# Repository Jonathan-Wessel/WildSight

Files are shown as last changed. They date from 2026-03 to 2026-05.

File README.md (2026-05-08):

# WildSights Rhino Detection Camera Node

This project is an ESP32-S3 wildlife monitoring camera node that detects rhinos using an Edge Impulse object detection model. The device is triggered by a PIR motion sensor, captures a grayscale image, runs inference on-device, saves the captured image to an SD card, and sends a LoRaWAN uplink message with the detection result.

The project is currently configured for the `ESP32S3-EYE` camera model.

---

## Features

- PIR motion-triggered image capture
- ESP32-S3 camera support
- Edge Impulse object detection
- Rhino detection using bounding box results
- Grayscale QVGA camera capture
- SD card image saving as JPEG
- LoRaWAN uplinks using LMIC
- IR LED control for low-light image capture
- FreeRTOS task for image capture and inference

---

## Important Board Manager Version

Use the following ESP32 board package version:

```text
ESP32 by Espressif Systems version 2.0.17
```

In the Arduino IDE:

1. Open **Tools > Board > Boards Manager**
2. Search for **esp32**
3. Install **esp32 by Espressif Systems**
4. Select version **2.0.17**

Using a newer or different ESP32 board package version may cause compatibility issues with the camera, PSRAM, SD card, or libraries.

---

## Hardware Requirements

- ESP32-S3 camera board
- ESP32S3-EYE compatible camera pin configuration
- PIR motion sensor
- IR LED or IR illuminator
- Light sensor
- SD card
- LoRa radio module
- LoRaWAN gateway
- LoRaWAN network server, such as The Things Network

---

## Software Requirements

- Arduino IDE
- ESP32 Arduino board package version `2.0.17`
- MCCI LoRaWAN LMIC library
- Edge Impulse Arduino library exported from the Edge Impulse project
- ESP32 camera support
- SD_MMC support

The sketch also requires these project files:

```cpp
#include "camera_pins.h"
#include "sd_read_write.h"
```

Make sure these files are included in the sketch folder or are available through the correct library or example source.

---

## Recommended Arduino IDE Settings

| Setting | Value |
|---|---|
| Board package | ESP32 by Espressif Systems `2.0.17` |
| Board | ESP32S3 Dev Module or compatible ESP32-S3 camera board |
| PSRAM | Enabled |
| Upload speed | 921600 or lower if upload fails |
| Serial monitor baud | 115200 |
| Partition scheme | Huge APP or another large-app partition |

The exact board option may depend on the ESP32-S3 camera board being used.

---

## Pin Configuration

### Sensor and Output Pins

| Function | GPIO |
|---|---:|
| PIR sensor | GPIO 1 |
| IR LED | GPIO 2 |
| Light sensor | GPIO 46 |

### LoRa Radio Pins

| Function | GPIO |
|---|---:|
| NSS / CS | GPIO 3 |
| RESET | GPIO 14 |
| DIO0 | GPIO 20 |
| DIO1 | GPIO 21 |
| MISO | GPIO 47 |
| MOSI | GPIO 19 |
| SCK | GPIO 45 |

These pins are defined in the sketch:

```cpp
#define GPIO_PIR         1
#define GPIO_IRLED       2
#define GPIO_LIGHTSENSOR 46

#define PIN_NSS   3
#define PIN_RST   14
#define PIN_DIO0  20
#define PIN_DIO1  21

#define LORA_MISO  47
#define LORA_MOSI  19
#define LORA_SCK   45
```

Check that the pin definitions match the actual wiring of your ESP32-S3 board and LoRa module.

---

## Camera Configuration

The project is configured for:

```cpp
#define CAMERA_MODEL_ESP32S3_EYE
```

The camera captures grayscale QVGA images:

```cpp
.pixel_format = PIXFORMAT_GRAYSCALE,
.frame_size   = FRAMESIZE_QVGA,
```

This means the camera captures images at:

```text
320 x 240
```

The frame buffer is stored in PSRAM:

```cpp
.fb_location = CAMERA_FB_IN_PSRAM
```

Because of this, PSRAM must be enabled in the Arduino IDE board settings.

---

## Edge Impulse Model

The project uses an exported Edge Impulse model:

```cpp
#include <Wildsights_rhino_md_conf.5_inferencing.h>
```

The classifier is initialized in `setup()`:

```cpp
run_classifier_init();
```

Inference is run using:

```cpp
EI_IMPULSE_ERROR err = run_classifier(&signal, &result, false);
```

The code checks the Edge Impulse bounding box results for the label:

```text
rhino
```

The label comparison happens here:

```cpp
if (strcmp(bb.label, "rhino") == 0)
```

If your Edge Impulse model uses a different label name, update this line in the sketch.

---

## Detection Threshold

The rhino detection confidence threshold is currently set to `0.7`:

```cpp
if (rhino && best.value >= 0.7) {
```

Threshold behavior:

| Threshold | Behavior |
|---|---|
| `0.5` | More sensitive, but may create more false positives |
| `0.7` | Current default |
| `0.9` | More strict, but may miss some detections |

---

## LoRaWAN Configuration

The sketch uses OTAA activation with:

- Join EUI
- Device EUI
- App Key

These values are defined in the code:

```cpp
static const uint8_t JOIN_EUI_BE[8] = { ... };
static const uint8_t DEV_EUI_BE[8]  = { ... };
static const uint8_t APP_KEY[16]    = { ... };
```

Do not publish real LoRaWAN credentials in a public repository.

For public repositories, replace real credentials with placeholder values:

```cpp
static const uint8_t JOIN_EUI_BE[8] = {
  0x00, 0x00, 0x00, 0x00,
  0x00, 0x00, 0x00, 0x00
};

static const uint8_t DEV_EUI_BE[8] = {
  0x00, 0x00, 0x00, 0x00,
  0x00, 0x00, 0x00, 0x00
};

static const uint8_t APP_KEY[16] = {
  0x00, 0x00, 0x00, 0x00,
  0x00, 0x00, 0x00, 0x00,
  0x00, 0x00, 0x00, 0x00,
  0x00, 0x00, 0x00, 0x00
};
```

If real keys were shared publicly, regenerate them in your LoRaWAN network server.

---

## LMIC Configuration

The LoRa radio uses custom SPI pins:

```cpp
SPI.begin(LORA_SCK, LORA_MISO, LORA_MOSI, PIN_NSS);
```

LMIC is initialized in `setup()`:

```cpp
os_init();
LMIC_reset();
LMIC_selectSubBand(1);
LMIC_setAdrMode(0);
LMIC_setClockError(MAX_CLOCK_ERROR * 1 / 100);
LMIC_startJoining();
```

The selected LoRaWAN sub-band is:

```cpp
LMIC_selectSubBand(1);
```

Make sure this matches your LoRaWAN region, gateway, and network server configuration.

---

## LoRaWAN Uplink Messages

When a rhino is detected, the node sends:

```text
Rhino detected
```

When no rhino is detected, the node sends:

```text
No Rhino
```

Messages are sent on LoRaWAN port `1`:

```cpp
LMIC_setTxData2(1, buf, (u1_t)len, 0);
```

---

## SD Card Image Saving

Images are saved to:

```text
/camera/
```

The directory is created during setup:

```cpp
createDir(SD_MMC, "/camera");
```

Images are saved using an incrementing file number:

```text
/camera/1.jpg
/camera/2.jpg
/camera/3.jpg
```

Both rhino detections and non-detections are currently saved.

---

## How It Works

1. The ESP32-S3 starts the serial monitor, SD card, camera, Edge Impulse model, LoRa radio, and PIR interrupt.
2. The PIR sensor triggers an interrupt when motion is detected.
3. A FreeRTOS inference task wakes up.
4. The PIR signal is debounced.
5. The IR LED turns on.
6. The camera captures a grayscale image.
7. The image is resized to the Edge Impulse model input size.
8. The Edge Impulse classifier runs on the ESP32-S3.
9. The result is checked for a bounding box labeled `rhino`.
10. If the confidence is at least `0.7`, a rhino detection is confirmed.
11. The image is saved to the SD card.
12. A LoRaWAN message is queued.
13. The IR LED turns off.
14. The system waits through a cooldown period before responding to another trigger.

---

## Main Runtime Loop

The main `loop()` only runs the LMIC event loop:

```cpp
void loop() {
  os_runloop_once();
}
```

Image capture and inference are handled in a separate FreeRTOS task:

```cpp
xTaskCreatePinnedToCore(
  inferenceTask,
  "inferenceTask",
  32768,
  nullptr,
  1,
  &inferTaskHandle,
  1
);
```

---

## Serial Monitor

Open the Serial Monitor at:

```text
115200 baud
```

Startup messages include:

```text
PSRAM found: YES
Free heap:
Free PSRAM:
Camera PID:
Setup complete.
```

LoRaWAN messages include:

```text
Joining...
JOINED!
Uplink queued: Rhino detected
TX complete
```

Inference messages include:

```text
INFERENCE: running classifier
INFERENCE: done classifier
Rhino DETECTED
No rhino.
```

---

## Troubleshooting

### Camera Init Failed

Check the following:

- The correct camera model is selected
- `camera_pins.h` matches your board
- PSRAM is enabled
- ESP32 board package version is `2.0.17`
- The camera ribbon cable is connected correctly

### Failed to Allocate Snapshot Buffer

Check the following:

- PSRAM is enabled
- The board has PSRAM
- The Edge Impulse model is not too large
- The partition scheme provides enough app space

### Device Does Not Join LoRaWAN

Check the following:

- Join EUI
- Device EUI
- App Key
- EUI byte order
- LMIC region
- LMIC sub-band
- Gateway frequency plan
- LoRa radio wiring
- Antenna connection

### SD Card Images Are Not Saving

Check the following:

- SD card is inserted
- SD card is formatted correctly
- `sdmmcInit()` succeeds
- The `/camera` directory exists
- `sd_read_write.h` is included correctly

### Classifier Always Returns No Rhino

Check the following:

- The model label is exactly `rhino`
- The detection threshold is not too high
- The camera image orientation is correct
- The IR LED provides enough illumination
- The training data matches the deployment environment
- The model was exported correctly from Edge Impulse

---

## Notes

The function:

```cpp
saveGrayJpegWithBox()
```

saves the grayscale camera frame as a JPEG image.

In the current version of the sketch, the bounding box is printed to the Serial Monitor but is not drawn onto the saved image.

The bounding box output is printed here:

```cpp
Serial.printf(
  "Rhino DETECTED label = %s : conf=%.3f box(x=%u y=%u w=%u h=%u)\n",
  best.label,
  best.value,
  best.x,
  best.y,
  best.width,
  best.height
);
```

---

## Deployment Notes

- Use a weatherproof enclosure for outdoor deployment.
- Protect the camera lens, PIR sensor, and electronics from rain.
- Use a stable power supply.
- Connect the LoRa antenna before transmitting.
- Test the camera, SD card, Edge Impulse model, and LoRaWAN join process before field deployment.
- Do not publish real LoRaWAN credentials.

---

## License

Add the project license here.

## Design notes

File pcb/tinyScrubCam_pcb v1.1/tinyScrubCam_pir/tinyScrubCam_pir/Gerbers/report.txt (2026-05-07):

Warning: Width correction constrained.  The width correction value must be in the range of [0.000001 mm; 0.199999 mm] for the current design rules.
Plotted to '/Users/ethanquach/Desktop/tinyScrubCam_pir/tinyScrubCam_pir/tinyScrubCam_pir-F_Cu.gbr'.
Plotted to '/Users/ethanquach/Desktop/tinyScrubCam_pir/tinyScrubCam_pir/tinyScrubCam_pir-B_Cu.gbr'.
Plotted to '/Users/ethanquach/Desktop/tinyScrubCam_pir/tinyScrubCam_pir/tinyScrubCam_pir-F_Paste.gbr'.
Plotted to '/Users/ethanquach/Desktop/tinyScrubCam_pir/tinyScrubCam_pir/tinyScrubCam_pir-B_Paste.gbr'.
Plotted to '/Users/ethanquach/Desktop/tinyScrubCam_pir/tinyScrubCam_pir/tinyScrubCam_pir-F_Silkscreen.gbr'.
Plotted to '/Users/ethanquach/Desktop/tinyScrubCam_pir/tinyScrubCam_pir/tinyScrubCam_pir-B_Silkscreen.gbr'.
Plotted to '/Users/ethanquach/Desktop/tinyScrubCam_pir/tinyScrubCam_pir/tinyScrubCam_pir-F_Mask.gbr'.
Plotted to '/Users/ethanquach/Desktop/tinyScrubCam_pir/tinyScrubCam_pir/tinyScrubCam_pir-B_Mask.gbr'.
Plotted to '/Users/ethanquach/Desktop/tinyScrubCam_pir/tinyScrubCam_pir/tinyScrubCam_pir-Edge_Cuts.gbr'.
Plotted to '/Users/ethanquach/Desktop/tinyScrubCam_pir/tinyScrubCam_pir/tinyScrubCam_pir-F_Courtyard.gbr'.
Created Gerber job file '/Users/ethanquach/Desktop/tinyScrubCam_pir/tinyScrubCam_pir/tinyScrubCam_pir-job.gbrjob'.
Info: Done.

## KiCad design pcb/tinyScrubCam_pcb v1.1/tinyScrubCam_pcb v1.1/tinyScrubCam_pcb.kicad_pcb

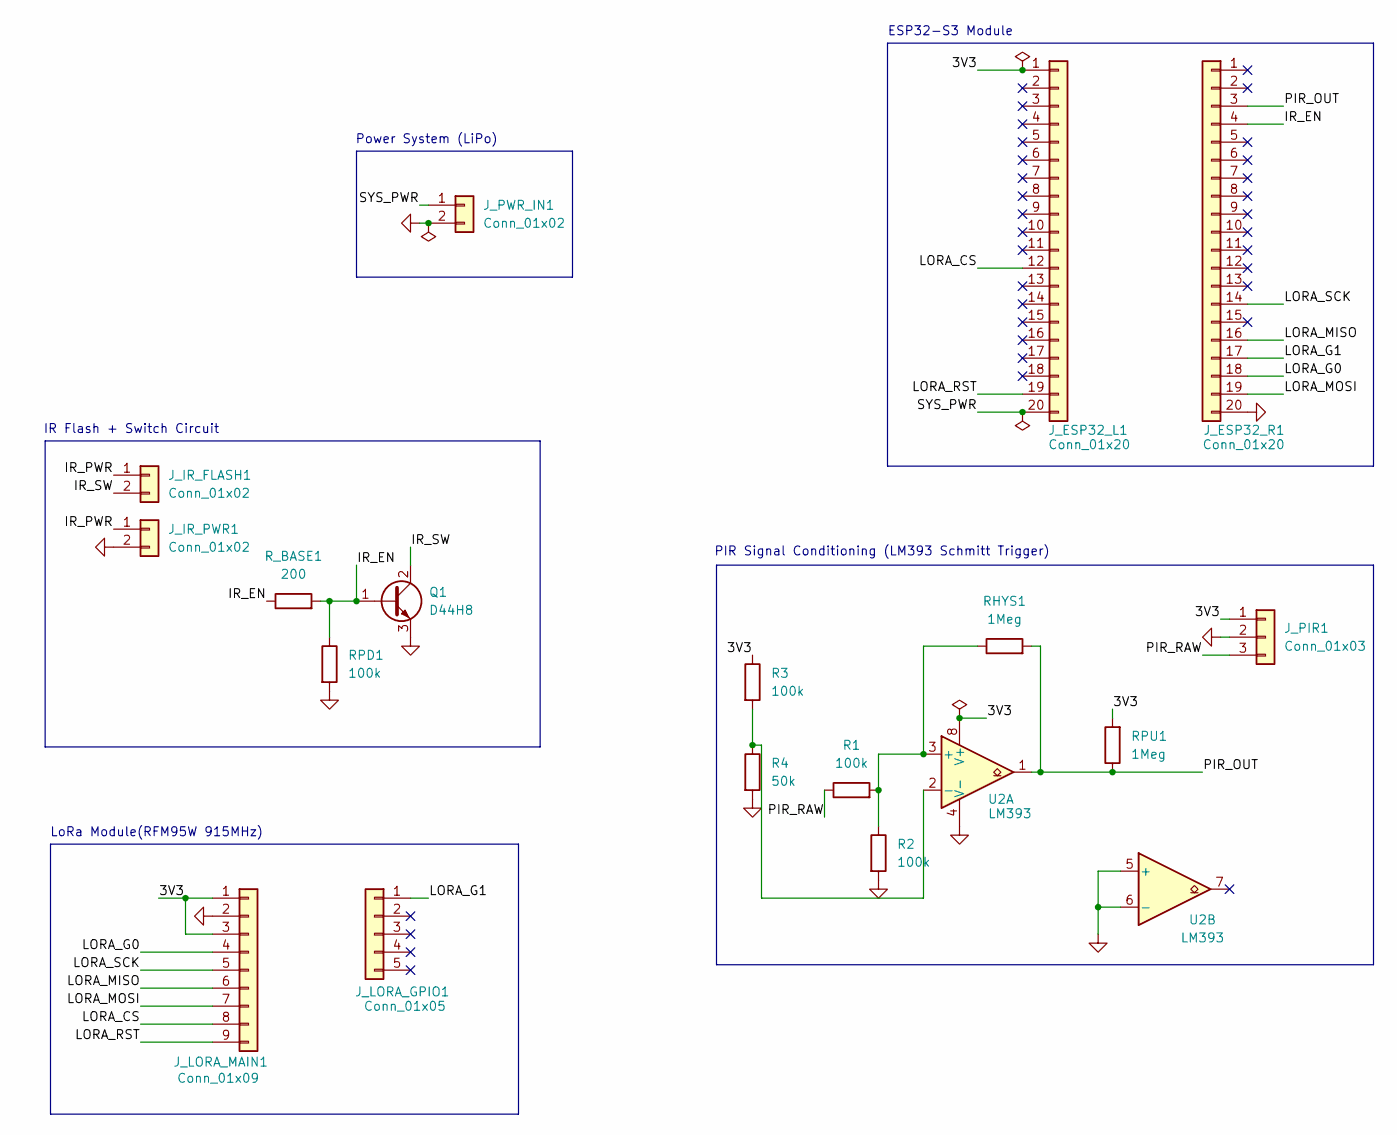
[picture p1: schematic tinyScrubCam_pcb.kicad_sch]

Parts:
J_ESP32_L1, J_ESP32_R1: Conn_01x20; PinHeader_1x20_P2.54mm_Vertical
J_IR_FLASH1: Conn_01x02; PinHeader_1x02_P2.54mm_Vertical
J_IR_PWR1: Conn_01x02; PinHeader_1x02_P2.54mm_Vertical
J_LORA_GPIO1: Conn_01x05; PinHeader_1x05_P2.54mm_Vertical
J_LORA_MAIN1: Conn_01x09; PinHeader_1x09_P2.54mm_Vertical
J_PIR1: Conn_01x03; PinSocket_1x03_P2.54mm_Vertical
J_PWR_IN1: Conn_01x02; JST_PH_B2B-PH-K_1x02_P2.00mm_Vertical
Q1: D44H8; TO-220-3_Vertical
R1, R2, R3: 100k; R_Axial_DIN0207_L6.3mm_D2.5mm_P10.16mm_Horizontal
R4: 50k; R_Axial_DIN0207_L6.3mm_D2.5mm_P10.16mm_Horizontal
RHYS1: 1Meg; R_Axial_DIN0207_L6.3mm_D2.5mm_P10.16mm_Horizontal
RPD1: 100k; R_Axial_DIN0207_L6.3mm_D2.5mm_P10.16mm_Horizontal
RPU1: 1Meg; R_Axial_DIN0207_L6.3mm_D2.5mm_P10.16mm_Horizontal
R_BASE1: 200; R_Axial_DIN0207_L6.3mm_D2.5mm_P10.16mm_Horizontal
U2: LM393

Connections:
/3V3: J_ESP32_L1.1 (3V3), J_LORA_MAIN1.1 (3V3), J_LORA_MAIN1.3 (EN), J_PIR1.1, R3.1, RPU1.2, U2.8 (V+); also elsewhere on the board
/IR_EN: J_ESP32_R1.4 (GPIO2), Q1.1 (B), RPD1.1, R_BASE1.1, R_BASE1.2
/IR_PWR: J_IR_FLASH1.1, J_IR_PWR1.1
/IR_SW: J_IR_FLASH1.2, Q1.2 (C)
/LORA_CS: J_ESP32_L1.12 (GPIO3), J_LORA_MAIN1.8 (CS)
/LORA_G0: J_ESP32_R1.18 (GPIO20), J_LORA_MAIN1.4 (GPIO0)
/LORA_G1: J_ESP32_R1.17 (GPIO21), J_LORA_GPIO1.1 (GPIO1_1)
/LORA_MISO: J_ESP32_R1.16 (GPIO47), J_LORA_MAIN1.6 (MISO)
/LORA_MOSI: J_ESP32_R1.19 (GPIO19), J_LORA_MAIN1.7 (MOSI)
/LORA_RST: J_ESP32_L1.19 (GPIO14), J_LORA_MAIN1.9 (RST)
/LORA_SCK: J_ESP32_R1.14 (GPIO45), J_LORA_MAIN1.5 (SCK)
/PIR_OUT: J_ESP32_R1.3 (GPIO1), RHYS1.2, RPU1.1, U2.1
/PIR_RAW: J_PIR1.3, R1.1; also elsewhere on the board
/SYS_PWR: J_ESP32_L1.20 (5V), J_PWR_IN1.1
GND: J_ESP32_R1.20 (GND), J_IR_PWR1.2, J_LORA_MAIN1.2 (GND), J_PIR1.2, J_PWR_IN1.2, Q1.3 (E), R2.2, R4.2, RPD1.2, U2.4 (V-), U2.5 (+), U2.6 (-); also elsewhere on the board
unnamed: R1.2, R2.1, RHYS1.1, U2.3 (+)
unnamed: R3.2, R4.1, U2.2 (-)

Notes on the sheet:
ESP32-S3 Module
IR Flash + Switch Circuit
Power System (LiPo)
LoRa Module(RFM95W 915MHz)
PIR Signal Conditioning (LM393 Schmitt Trigger)

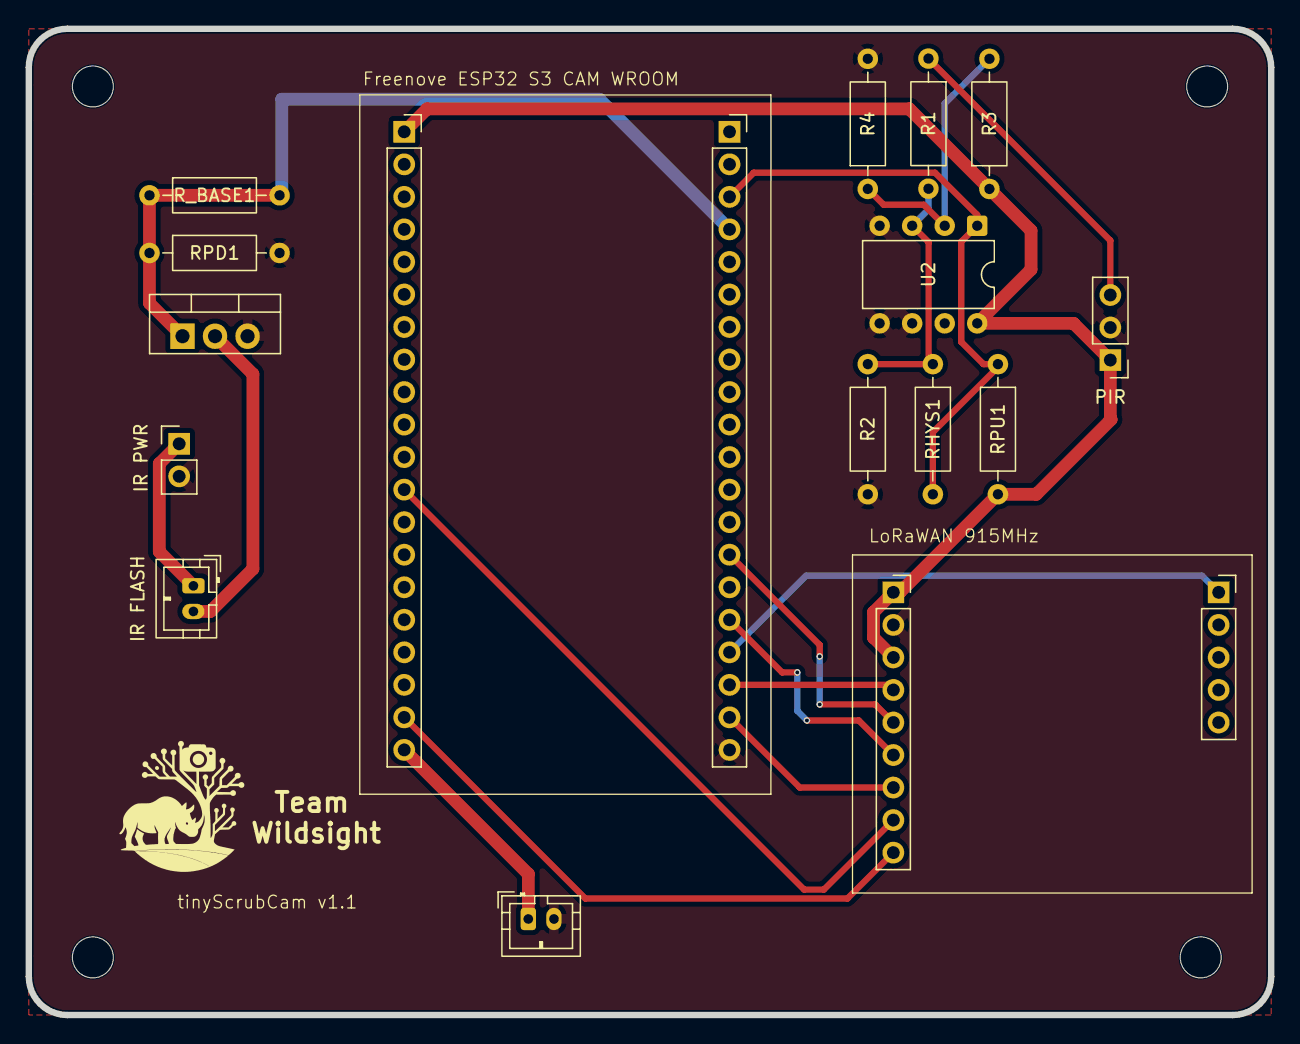
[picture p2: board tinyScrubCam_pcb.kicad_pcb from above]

Board: 2 copper layers, 97.0 x 77.0 mm, 18 parts (0 on the bottom side), 17 nets.

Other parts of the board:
PIR: Conn_01x03; PinHeader_1x03_P2.54mm_Vertical

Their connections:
/3V3: PIR.1; also elsewhere on the board
/PIR_RAW: PIR.3; also elsewhere on the board
GND: PIR.2; also elsewhere on the board

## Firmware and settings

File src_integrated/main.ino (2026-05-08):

// =================== Camera / SD / LEDs ===================
#include "esp_camera.h"
#define CAMERA_MODEL_ESP32S3_EYE
#include "camera_pins.h"
#include "sd_read_write.h"
#include "img_converters.h"   // fmt2jpg()

// =================== Arduino / LMIC / SPI ===================
#include <Arduino.h>
#include <lmic.h>
#include <hal/hal.h>
#include <SPI.h>
#include <string.h>

// =================== Edge Impulse ===================
#include <Wildsights_rhino_md_conf.5_inferencing.h>
#include "edge-impulse-sdk/dsp/image/image.hpp"
#include "esp_heap_caps.h"

// =================== FreeRTOS ===================draw
#include "freertos/FreeRTOS.h"
#include "freertos/task.h"

// =================== GPIO ===================
#define GPIO_PIR         1
#define GPIO_IRLED       2
#define GPIO_LIGHTSENSOR 46   // don’t share with NSS etc.

// LoRa pins
#define PIN_NSS   3
#define PIN_RST   14
#define PIN_DIO0  20
#define PIN_DIO1  21

// Custom SPI pins for LoRa radio
#define LORA_MISO  47
#define LORA_MOSI  19
#define LORA_SCK   45

// =================== LoRaWAN KEYS ===================
static const uint8_t JOIN_EUI_BE[8] = { 0,0,0,0,0,0,0,0 };
static const uint8_t DEV_EUI_BE[8]  = { 0x70,0xB3,0xD5,0x7E,0xD8,0x00,0x50,0x7F };
static const uint8_t APP_KEY[16]    = {
  0x6E,0x2C,0xB9,0x5B,0x06,0x57,0x13,0x4B,
  0x9B,0xCC,0xEC,0x15,0xB6,0x5C,0x51,0x74
};

void os_getArtEui (u1_t* buf) { for (int i=0;i<8;i++) buf[i] = JOIN_EUI_BE[7-i]; }
void os_getDevEui (u1_t* buf) { for (int i=0;i<8;i++) buf[i] = DEV_EUI_BE[7-i]; }
void os_getDevKey (u1_t* buf) { memcpy(buf, APP_KEY, 16); }

// LMIC pin mapping
const lmic_pinmap lmic_pins = {
  .nss = PIN_NSS,
  .rxtx = LMIC_UNUSED_PIN,
  .rst = PIN_RST,
  .dio = { PIN_DIO0, PIN_DIO1, LMIC_UNUSED_PIN }
};

static osjob_t sendjob;

// =================== LoRa payload queue ===================
static char pendingMsg[51];
static volatile bool havePendingMsg = false;

void do_send(osjob_t*);

bool sendString(const char* s) {
  if (!s) return false;
  size_t len = strnlen(s, sizeof(pendingMsg)-1);
  if (len == 0) return false;

  memset(pendingMsg, 0, sizeof(pendingMsg));
  memcpy(pendingMsg, s, len);
  havePendingMsg = true;

  do_send(&sendjob);
  return true;
}

void queueSendRhinoDetected() {
  sendString("Rhino detected");
}

void do_send(osjob_t*) {
  if (LMIC.devaddr == 0) return;          // not joined yet
  if (LMIC.opmode & OP_TXRXPEND) {        // radio busy
    os_setTimedCallback(&sendjob, os_getTime() + ms2osticks(300), do_send);
    return;
  }
  if (!havePendingMsg) return;

  uint8_t buf[51];
  size_t len = strnlen(pendingMsg, sizeof(pendingMsg));
  memcpy(buf, pendingMsg, len);

  LMIC_setTxData2(1, buf, (u1_t)len, 0);
  Serial.print("Uplink queued: ");
  Serial.println(pendingMsg);

  havePendingMsg = false;
}

void onEvent(ev_t ev) {
  Serial.print("[LMIC] ");
  Serial.println((unsigned)ev);

  if (ev == EV_JOINING) Serial.println("Joining...");
  if (ev == EV_JOINED) {
    Serial.println("JOINED!");
    LMIC_setLinkCheckMode(0);
    do_send(&sendjob);
  }
  if (ev == EV_JOIN_FAILED) {
    Serial.println("Join failed (keys/subband/pins/frequency-plan issue)");
  }
  if (ev == EV_TXCOMPLETE) {
    Serial.println("TX complete");
  }
}

// =================== Camera config (GRAYSCALE QVGA) ===================
static bool cam_init_ok = false;

static camera_config_t cam_cfg = {
  .pin_pwdn = PWDN_GPIO_NUM,
  .pin_reset = RESET_GPIO_NUM,
  .pin_xclk = XCLK_GPIO_NUM,
  .pin_sscb_sda = SIOD_GPIO_NUM,
  .pin_sscb_scl = SIOC_GPIO_NUM,

  .pin_d7 = Y9_GPIO_NUM,
  .pin_d6 = Y8_GPIO_NUM,
  .pin_d5 = Y7_GPIO_NUM,
  .pin_d4 = Y6_GPIO_NUM,
  .pin_d3 = Y5_GPIO_NUM,
  .pin_d2 = Y4_GPIO_NUM,
  .pin_d1 = Y3_GPIO_NUM,
  .pin_d0 = Y2_GPIO_NUM,
  .pin_vsync = VSYNC_GPIO_NUM,
  .pin_href = HREF_GPIO_NUM,
  .pin_pclk = PCLK_GPIO_NUM,

  .xclk_freq_hz = 5000000,
  .ledc_timer = LEDC_TIMER_0,
  .ledc_channel = LEDC_CHANNEL_0,

  .pixel_format = PIXFORMAT_GRAYSCALE,
  .frame_size   = FRAMESIZE_QVGA,        // 320x240
  .jpeg_quality = 12,
  .fb_count     = 1,
  .fb_location  = CAMERA_FB_IN_PSRAM,
  .grab_mode    = CAMERA_GRAB_WHEN_EMPTY,
};

static uint8_t *snapshot_buf = nullptr;
static size_t snapshot_buf_size = 0;

//Camera Initialization Function
bool cameraInitGray() {
  if (cam_init_ok) return true;

  esp_err_t err = esp_camera_init(&cam_cfg);
  if (err != ESP_OK) {
    Serial.printf("Camera init failed: 0x%x\n", err);
    return false;
  }

  sensor_t *s = esp_camera_sensor_get();
  Serial.printf("Camera PID: 0x%02x\n", s->id.PID);

      if (s->id.PID == OV3660_PID) {
      s->set_vflip(s, 1); // flip it back
      s->set_brightness(s, 1); // up the brightness just a bit
      s->set_saturation(s, 0); // lower the saturation
    }

  cam_init_ok = true;
  return true;
}

// EI data feed
static int ei_camera_get_data(size_t offset, size_t length, float *out_ptr) {
    size_t pixel_ix = offset;
    size_t pixels_left = length;

    while (pixels_left != 0) {
        out_ptr[0] = (float)snapshot_buf[pixel_ix];
        out_ptr++;
        pixel_ix++;
        pixels_left--;
    }

    return 0;
}

// Save latest GRAYSCALE frame as JPEG, optionally drawing a bbox first
bool saveGrayJpegWithBox(camera_fb_t *fb) {
  if (!fb) {
    Serial.println("saveGrayJpegWithBox: fb is null");
    return false;
  }

  if (fb->format != PIXFORMAT_GRAYSCALE) {
    Serial.printf("saveGrayJpegWithBox: wrong format %d\n", fb->format);
    return false;
  }

  uint8_t *jpg_buf = nullptr;
  size_t jpg_len = 0;

  Serial.printf("Encoding JPEG from grayscale: w=%u h=%u len=%u\n",
                fb->width, fb->height, fb->len);

  bool ok = fmt2jpg(
    fb->buf, fb->len,
    fb->width, fb->height,
    PIXFORMAT_GRAYSCALE,
    80,
    &jpg_buf, &jpg_len
  );

  Serial.printf("fmt2jpg ok=%d jpg_buf=%p jpg_len=%u freeHeap=%u\n",
                ok ? 1 : 0,
                jpg_buf,
                (unsigned)jpg_len,
                (unsigned)ESP.getFreeHeap());

  if (!ok || !jpg_buf || jpg_len < 2) {
    Serial.println("JPEG encode failed");
    if (jpg_buf) free(jpg_buf);
    return false;
  }

  int idx = readFileNum(SD_MMC, "/camera");
  if (idx < 0) {
    Serial.println("readFileNum failed");
    free(jpg_buf);
    return false;
  }

  String path = "/camera/" + String(idx) + ".jpg";

  bool write_ok = writejpg(SD_MMC, path.c_str(), jpg_buf, jpg_len);
  if (write_ok) {
    Serial.print("Saved: ");
    Serial.println(path);
  } else {
    Serial.print("Failed to save: ");
    Serial.println(path);
  }

  free(jpg_buf);
  return write_ok;
}

static bool getBestRhinoBox(const ei_impulse_result_t &result, ei_impulse_result_bounding_box_t &best) {
  best = {0};

#if EI_CLASSIFIER_OBJECT_DETECTION == 1
  bool found = false;
  for (size_t i = 0; i < result.bounding_boxes_count; i++) {
    ei_impulse_result_bounding_box_t bb = result.bounding_boxes[i];
    if (bb.label == nullptr) continue;

            ei_printf("  %s (%f) [ x: %u, y: %u, width: %u, height: %u ]\r\n",
                bb.label,
                bb.value,
                bb.x,
                bb.y,
                bb.width,
                bb.height);

    // Relaxed match: Check if "rhino" is anywhere in the label
    if (strcmp(bb.label, "rhino") == 0) {
      if (!found || bb.value > best.value) {
        best = bb;
        found = true;
      }
    }
  }
  return found;
#else
  (void)result;
  return false;
#endif
}

static bool ei_resize_from_fb(camera_fb_t *fb, uint32_t img_width, uint32_t img_height, uint8_t *out_buf) {
    if (!fb) {
        ei_printf("ERR: fb is null\n");
        return false;
    }

    if (fb->format != PIXFORMAT_GRAYSCALE) {
        ei_printf("ERR: expected GRAYSCALE fb, got %d\n", (int)fb->format);
        return false;
    }

    const uint32_t src_w = fb->width;
    const uint32_t src_h = fb->height;

    if (src_w == 0 || src_h == 0 || img_width == 0 || img_height == 0) {
        ei_printf("ERR: invalid dimensions\n");
        return false;
    }

    // FIT_SHORTEST:
    // Scale so the shortest source axis fills the destination,
    // then center-crop the overflow on the longer axis.
    const float scale_x = (float)img_width / (float)src_w;
    const float scale_y = (float)img_height / (float)src_h;
    const float scale = (scale_x > scale_y) ? scale_x : scale_y;

    const float scaled_w = src_w * scale;
    const float scaled_h = src_h * scale;

    const float crop_x_scaled = (scaled_w - img_width) * 0.5f;
    const float crop_y_scaled = (scaled_h - img_height) * 0.5f;

    for (uint32_t y = 0; y < img_height; y++) {
        for (uint32_t x = 0; x < img_width; x++) {
            // Destination pixel -> scaled-source space
            float sx_scaled = x + crop_x_scaled;
            float sy_scaled = y + crop_y_scaled;

            // Scaled-source space -> original source space
            float sx = sx_scaled / scale;
            float sy = sy_scaled / scale;

            // Nearest neighbor
            int src_x = (int)(sx + 0.5f);
            int src_y = (int)(sy + 0.5f);

            if (src_x < 0) src_x = 0;
            if (src_y < 0) src_y = 0;
            if (src_x >= (int)src_w) src_x = (int)src_w - 1;
            if (src_y >= (int)src_h) src_y = (int)src_h - 1;

            out_buf[y * img_width + x] = fb->buf[src_y * src_w + src_x];
        }
    }

    return true;
}

// =================== PIR semaphore + task ===================
SemaphoreHandle_t pir_sem = nullptr;
TaskHandle_t inferTaskHandle = nullptr;

void IRAM_ATTR onPirISR() {
  BaseType_t hp = pdFALSE;
  if (pir_sem) xSemaphoreGiveFromISR(pir_sem, &hp);
  if (hp) portYIELD_FROM_ISR();
}

void inferenceTask(void *param) {
  (void)param;
  Serial.printf("inferenceTask running on core %d\n", xPortGetCoreID());

  while (true) {
    xSemaphoreTake(pir_sem, portMAX_DELAY);

    // Debounce
    vTaskDelay(pdMS_TO_TICKS(50));
    if (digitalRead(GPIO_PIR) != HIGH) continue;


    for (int i = 0; i < 2; i++) {
      camera_fb_t *tmp = esp_camera_fb_get();
      if (tmp) esp_camera_fb_return(tmp);
      vTaskDelay(pdMS_TO_TICKS(10));
    }

    // instead of wait_ms, we'll wait on the signal, this allows threads to cancel us...
        if (ei_sleep(5) != EI_IMPULSE_OK) {
            return;
        }

    ei::signal_t signal;
    signal.total_length = EI_CLASSIFIER_RAW_SAMPLE_COUNT;
    signal.get_data = &ei_camera_get_data;

    digitalWrite(GPIO_IRLED, HIGH);
    delay(500);
    camera_fb_t *fb = esp_camera_fb_get();
    
      if (!fb) {
          Serial.printf("Camera capture failed\r\n");
          digitalWrite(GPIO_IRLED, LOW);
          continue;
      }

      Serial.printf("fb format=%d w=%d h=%d len=%u\r\n",
              (int)fb->format, fb->width, fb->height, (unsigned)fb->len);

      Serial.printf("capturing...\n");
      if (!ei_resize_from_fb(fb, EI_CLASSIFIER_INPUT_WIDTH, EI_CLASSIFIER_INPUT_HEIGHT, snapshot_buf)) {
          Serial.printf("Failed to resize image\r\n");
          esp_camera_fb_return(fb);
          continue;
      }
      Serial.printf("done capturing\n");

    Serial.printf("INFERENCE: running classifier\n");
    ei_impulse_result_t result = {0};
    EI_IMPULSE_ERROR err = run_classifier(&signal, &result, false);
    Serial.printf("INFERENCE: done classifier\n");
   
    if (err != EI_IMPULSE_OK) {
      Serial.printf("run_classifier failed (%d)\n", err);
      //ws2812SetColor(1);
      continue;
    }

    // ---- Decide rhino + bbox ----
    ei_impulse_result_bounding_box_t best;
    bool rhino = getBestRhinoBox(result, best);

    if (rhino && best.value >= 0.7) {
      Serial.printf("Rhino DETECTED ✅ label = %s : conf=%.3f box(x=%u y=%u w=%u h=%u)\n",
                    best.label, best.value, best.x, best.y, best.width, best.height);

      //ws2812SetColor(2);


      if (!saveGrayJpegWithBox(fb)) {
          Serial.println("Save failed");
      }

      // Send LoRa
      queueSendRhinoDetected();
    }
    else {
      Serial.println("No rhino.");
      //ws2812SetColor(1);
      if (!saveGrayJpegWithBox(fb)) {
          Serial.println("Save failed");
      }
      sendString("No Rhino");
      // Optional: save non-detections too
    }

    digitalWrite(GPIO_IRLED, LOW);

    // Cooldown
    vTaskDelay(pdMS_TO_TICKS(5000));

    esp_camera_fb_return(fb);
  }
}

// =================== Setup / Loop ===================
void setup() {
  Serial.begin(115200);
  delay(1500);
  Serial.printf("PSRAM found: %s\n", psramFound() ? "YES" : "NO");
  Serial.printf("Free heap: %u\n", ESP.getFreeHeap());
  Serial.printf("Free PSRAM: %u\n", ESP.getFreePsram());

  pinMode(GPIO_PIR, INPUT);
  pinMode(GPIO_IRLED, OUTPUT);
  digitalWrite(GPIO_IRLED, LOW);
  pinMode(GPIO_LIGHTSENSOR, INPUT);

  //ws2812Init();

  // SD
  sdmmcInit();
  createDir(SD_MMC, "/camera");
  listDir(SD_MMC, "/camera", 0);

  // Camera
  if (!cameraInitGray()) {
    Serial.println("Camera init failed");
    while (1) delay(1000);
  }

  // EI buffer: for grayscale models RAW_SAMPLE_COUNT is usually W*H
  snapshot_buf_size = EI_CLASSIFIER_RAW_SAMPLE_COUNT;
  snapshot_buf = (uint8_t*)heap_caps_malloc(snapshot_buf_size, MALLOC_CAP_SPIRAM | MALLOC_CAP_8BIT);
  if (!snapshot_buf) {
    Serial.println("Failed to allocate snapshot buffer");
    while (1) delay(1000);
  }
  run_classifier_init();

  // LoRa
  SPI.begin(LORA_SCK, LORA_MISO, LORA_MOSI, PIN_NSS);
  os_init();
  LMIC_reset();
  LMIC_selectSubBand(1);
  LMIC_setAdrMode(0);
  LMIC_setClockError(MAX_CLOCK_ERROR * 1 / 100);
  LMIC_startJoining();

  //PIR semaphore + ISR
  pir_sem = xSemaphoreCreateBinary();
  attachInterrupt(digitalPinToInterrupt(GPIO_PIR), onPirISR, RISING);

  // Inference task
  xTaskCreatePinnedToCore(inferenceTask, "inferenceTask", 32768, nullptr, 1, &inferTaskHandle, 1);

  Serial.println("Setup complete.");
}

void loop() {
  os_runloop_once();
}

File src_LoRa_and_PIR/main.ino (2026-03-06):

#include "esp_camera.h"
#define CAMERA_MODEL_ESP32S3_EYE
#include "camera_pins.h"
#include "ws2812.h"
#include "sd_read_write.h"

#include <Arduino.h>
#include <lmic.h>
#include <hal/hal.h>
#include <SPI.h>
#include <string.h>

#define BUTTON_PIN 0
#define GPIO_PIR 1
#define GPIO_IRLED 2
#define GPIO_LIGHTSENSOR 46

// LoRa pins
#define PIN_NSS  3   // CS/NSS
#define PIN_RST  14  // RESET
#define PIN_DIO0 20  // DIO0
#define PIN_DIO1 21  // DIO1

// Custom SPI pins
#define LORA_MISO 47
#define LORA_MOSI 19
#define LORA_SCK  45

// =================== LoRaWAN KEYS ===================
static const uint8_t JOIN_EUI_BE[8] = {
  0x00,0x00,0x00,0x00,0x00,0x00,0x00,0x00
};

static const uint8_t DEV_EUI_BE[8]  = {
  0x70,0xB3,0xD5,0x7E,0xD8,0x00,0x50,0x7F
};

static const uint8_t APP_KEY[16]    = {
  0x6E,0x2C,0xB9,0x5B,0x06,0x57,0x13,0x4B,
  0x9B,0xCC,0xEC,0x15,0xB6,0x5C,0x51,0x74
};

void os_getArtEui (u1_t* buf) {
  for (int i = 0; i < 8; i++) buf[i] = JOIN_EUI_BE[7 - i];
}

void os_getDevEui (u1_t* buf) {
  for (int i = 0; i < 8; i++) buf[i] = DEV_EUI_BE[7 - i];
}

void os_getDevKey (u1_t* buf) {
  memcpy(buf, APP_KEY, 16);
}

const lmic_pinmap lmic_pins = {
  .nss = PIN_NSS,
  .rxtx = LMIC_UNUSED_PIN,
  .rst = PIN_RST,
  .dio = { PIN_DIO0, PIN_DIO1, LMIC_UNUSED_PIN }
};

static osjob_t sendjob;

// ---- Payload queue ----
static char pendingMsg[51];              // keep <= 51 for safety at lower DRs
static volatile bool havePendingMsg = false;

// Forward decl
void do_send(osjob_t*);

// Queue any string payload (ASCII)
bool sendString(const char* s) {
  if (s == nullptr) return false;

  size_t len = strnlen(s, sizeof(pendingMsg) - 1);
  if (len == 0) return false;

  // Store it for sending
  memset(pendingMsg, 0, sizeof(pendingMsg));
  memcpy(pendingMsg, s, len);
  havePendingMsg = true;

  // Try immediate send (or it will retry from do_send)
  do_send(&sendjob);
  return true;
}

// Call this from your camera/model code when rhino is confirmed
void queueSendRhinoDetected() {
  sendString("Rhino detected");
}

void do_send(osjob_t*) {
  // Must be joined (LMIC.devaddr becomes non-zero after join)
  if (LMIC.devaddr == 0) {
    // not joined yet; keep message pending
    return;
  }

  // Radio busy?
  if (LMIC.opmode & OP_TXRXPEND) {
    // retry soon
    os_setTimedCallback(&sendjob, os_getTime() + ms2osticks(500), do_send);
    return;
  }

  if (!havePendingMsg) return;

  // Convert message to bytes (no null terminator)
  uint8_t buf[51];
  size_t len = strnlen(pendingMsg, sizeof(pendingMsg));
  memcpy(buf, pendingMsg, len);

  LMIC_setTxData2(/*port*/1, buf, (u1_t)len, /*confirmed*/0);

  Serial.print("Uplink queued: ");
  Serial.println(pendingMsg);

  havePendingMsg = false;
}

void onEvent(ev_t ev) {
  Serial.print("[LMIC] ");
  Serial.println((unsigned)ev);

  if (ev == EV_JOINING) Serial.println("Joining...");

  if (ev == EV_JOINED) {
    Serial.println("JOINED!");
    LMIC_setLinkCheckMode(0);

    // If something was queued before join completed, send it now
    do_send(&sendjob);
  }

  if (ev == EV_JOIN_FAILED || ev == EV_JOIN_TXCOMPLETE) {
    Serial.println("Join not accepted (keys/subband/pins/frequency-plan issue)");
  }

  if (ev == EV_TXCOMPLETE) {
    Serial.println("TX complete");

    // Optional: schedule periodic retry send if you want periodic telemetry.
    // For your case (event-based), you can remove this entirely.
    // os_setTimedCallback(&sendjob, os_getTime() + sec2osticks(30), do_send);
  }
}

void LoRa_setup() {
  Serial.begin(115200);
  delay(1500);

  SPI.begin(LORA_SCK, LORA_MISO, LORA_MOSI, PIN_NSS);

  os_init();
  LMIC_reset();

  // US915 subband (adjust to match your gateway FSB)
  LMIC_selectSubBand(1);

  LMIC_setAdrMode(0);
  LMIC_setClockError(MAX_CLOCK_ERROR * 1 / 100);

  LMIC_startJoining();

  // --- TEST: comment this out once you hook camera trigger ---
  // queueSendRhinoDetected();
}

void PIR_setup() {
  Serial.begin(115200);
  Serial.setDebugOutput(false);
  Serial.println();

  pinMode(BUTTON_PIN, INPUT_PULLUP);
  pinMode(GPIO_PIR, INPUT);
  pinMode(GPIO_IRLED, OUTPUT);
  pinMode(GPIO_LIGHTSENSOR, INPUT);

  ws2812Init();
  sdmmcInit();

  // removeDir(SD_MMC, "/camera");
  createDir(SD_MMC, "/camera");
  listDir(SD_MMC, "/camera", 0);

  if (cameraSetup() == 1) {
    ws2812SetColor(2);
  } else {
    ws2812SetColor(1);
    return;
  }

  delay(10000);
}

int cameraSetup(void) {
  camera_config_t config;
  config.ledc_channel = LEDC_CHANNEL_0;
  config.ledc_timer = LEDC_TIMER_0;
  config.pin_d0 = Y2_GPIO_NUM;
  config.pin_d1 = Y3_GPIO_NUM;
  config.pin_d2 = Y4_GPIO_NUM;
  config.pin_d3 = Y5_GPIO_NUM;
  config.pin_d4 = Y6_GPIO_NUM;
  config.pin_d5 = Y7_GPIO_NUM;
  config.pin_d6 = Y8_GPIO_NUM;
  config.pin_d7 = Y9_GPIO_NUM;
  config.pin_xclk = XCLK_GPIO_NUM;
  config.pin_pclk = PCLK_GPIO_NUM;
  config.pin_vsync = VSYNC_GPIO_NUM;
  config.pin_href = HREF_GPIO_NUM;
  config.pin_sccb_sda = SIOD_GPIO_NUM;
  config.pin_sccb_scl = SIOC_GPIO_NUM;
  config.pin_pwdn = PWDN_GPIO_NUM;
  config.pin_reset = RESET_GPIO_NUM;
  config.xclk_freq_hz = 10000000;
  config.frame_size = FRAMESIZE_UXGA;
  config.pixel_format = PIXFORMAT_JPEG; // for streaming
  config.grab_mode = CAMERA_GRAB_WHEN_EMPTY;
  config.fb_location = CAMERA_FB_IN_PSRAM;
  config.jpeg_quality = 12;
  config.fb_count = 1;

  // if PSRAM IC present, init with UXGA resolution and higher JPEG quality
  // for larger pre-allocated frame buffer.
  if (psramFound()) {
    config.jpeg_quality = 10;
    config.fb_count = 2;
    config.grab_mode = CAMERA_GRAB_LATEST;
  } else {
    // Limit the frame size when PSRAM is not available
    config.frame_size = FRAMESIZE_SVGA;
    config.fb_location = CAMERA_FB_IN_DRAM;
  }

  // camera init
  esp_err_t err = esp_camera_init(&config);
  if (err != ESP_OK) {
    Serial.printf("Camera init failed with error 0x%x", err);
    return 0;
  }

  sensor_t * s = esp_camera_sensor_get();
  // initial sensors are flipped vertically and colors are a bit saturated
  s->set_vflip(s, 1);       // flip it back
  s->set_brightness(s, 1);  // up the brightness just a bit
  s->set_saturation(s, 0);  // lower the saturation

  Serial.println("Camera configuration complete!");
  return 1;
}

void PIR_Loop() {
  if (digitalRead(GPIO_PIR) == HIGH) {
    delay(20);

    if (digitalRead(GPIO_PIR) == HIGH) {
      ws2812SetColor(3);

      while (digitalRead(GPIO_PIR) == HIGH) {
        // wait for PIR to go low again
      }

      camera_fb_t * fb = nullptr;
      fb = esp_camera_fb_get();

      if (fb != nullptr) {
        int photo_index = readFileNum(SD_MMC, "/camera");
        if (photo_index != -1) {
          String path = "/camera/" + String(photo_index) + ".jpg";
          writejpg(SD_MMC, path.c_str(), fb->buf, fb->len);
        }
        esp_camera_fb_return(fb);
      } else {
        Serial.println("Camera capture failed.");
      }

      ws2812SetColor(2);
      queueSendRhinoDetected();
    }

    delay(5000);
  }
}
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

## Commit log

2026-02-03 Added the LoRa, and fixed ReadMe and Folders
    [LoRa-sending.ino, SeniorDesignBaseSketch.ino, sd_read_write.cpp]
2026-02-19 Current EdgeImpulseModel code and saves images to microSD
